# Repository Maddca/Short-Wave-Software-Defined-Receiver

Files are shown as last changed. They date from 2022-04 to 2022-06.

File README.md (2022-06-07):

# Short-Wave-Software-Defined-Receiver
The goal of this project has been to design a Software Defined Radio Receiver with [Taylor Smith](https://github.com/TaylorSmith28) for the Engineering Electronics II class.
## Design Objectives
For this project we were given the following design objectives by [Dr. Rob Frohne](https://github.com/frohro):

#### Objectives
 - Low noise figure
 - Good image rejection
 - Minimum discernible signal of less than 1uV
 - $25 Budget

For specifications we originally were going to have a narrow bandpass filter, but ended up switching to a relatively wider one in the later stages of the project.

#### Specifications
 - Frequency Range of 7-12MHz
 - Short Wave Radio
 - Uses a Tayloe Mixer
 - Uses a Multiple Feedback Lowpass Filter and Amplifier
 	- 25 V/V gain with Cutoff Frequency of more than 50KHz
 - Butterworth Bandpass Filter
 - Uses the Raspberry Pi Pico
 
 ## Overview
 The SDR receiver connects to an antenna and filters, mixes, and amplifies that signal to achieve the desired I and Q signals. The I and Q signals are then sent through an external sound card with a sample rate of 48kHz where software then handles the demodulation of the signal into audio. The mixer requires a 90 degree offset of two clocks operating at a frequency that can be controlled through software. In our design we use a Raspberry Pi Pico to control an si5351 to supply those two 90 degree offset clocks. There were some significant issues with this since the code supplied by professor Frohne didn't work when ported over to the Raspberry Pi Pico. In theory though the Raspberry Pi Pico interfaces with Quisk to tune to a certain frequency by adjusting the frequency of the si5351 clocks.
 
 ## Theory
SDR Block Diagram

The Block Diagram above shows the basics of how the SDR works. We get an input signal from the antenna which is passed through the bandpass filter and sent to the Tayloe Mixer that uses a 1:4 demultiplexer and low pass filters and ampliers to create the I and Q quardrature signals. After the demuiltiplexer creates 4 signals each 90 degrees out of phase with each other those signals are combined together to create the I and Q signals to be sent to the Audio Jack.

## Schematic Version 6

### Bandpass Filter
SDR BandPass Filter V6
 Above is the bandpass filter made using the [LC Filter Design Tool](https://rf-tools.com/lc-filter/.). It is a 3rd order, conventional series first, Butterworth, bandpass filter that passes 7-12Mhz frequencies.
 
 ### Tayloe Mixer
 SDR Tayloe Mixer
The Tayloe Mixer above is comprised of the Demultiplexer stage which seperates the input signal into four signals all 90 degrees out of phase with each other. Then the signals that are 180 degrees out of phase with each other are combined in the following amplifier and low pass filter stage using opamps. The filter/amplifier here is a multiple feedback low pass filter and amplifier, in this case multiple refers to the filter being second order rather than single order.

### Voltage Smoother
SDR Voltage Smoother
The voltage smoother above simply uses varying capacitor sizes to lower the noise coming from the USB.

### Oscillator
SDR Oscillator
The oscillator above is what outputs the clock signals necessary to run the Tayloe Mixer. It is controlled by the Raspberry Pi Pico on the SDA and SCL inputs.

### Raspberry Pi Pico
SDR Raspberry Pi Pico
Above is the part of the schematic dealing with the Raspberry Pi Pico. The main thing of interest here is to note the pull up resistors and the GPIO pin the SDA and SCL are connected to, since the pin needs to be I2C compatible, in this case pins 6 and 7 or GPIO 4 and 5 are I2C compatible.

## Simulations
Simulations were for the most part conducted in [LTSpice](https://www.analog.com/en/design-center/design-tools-and-calculators/ltspice-simulator.html).
### Bandpass Filter Simulations
SDR Bandpass Filter Sim Graph
SDR BandPass Filter LTSpice
The Bandpass filter was designed to pass frequencies between 7 and 12 MHz, which is what the ac simulation shows.

### Lowpass Filter Simulations
SDR MFLPFA Simulation Graph
SDR MFLPFA LTSpice

## Issues
The first major issue we encountered was not having functional code because of the port over to Raspberry Pi Pico. It took 2 days of troubleshooting to get the appropriate clock signal to display and thats still without the ability to change frequencies, which currently causes the program to hang. The second major issue was much simpler. When we went to test our bandpass filter we came to the realization that one of the leads on the handwound inductors couldn't make a good connection because there was still enamel on it. After several failed attempts to remove it we decided jump the bandpass filter, but much later discovered that shorting the bandpass filter with a wire caused one of the resistors responsible for the dc offset to be in parallel with the resistor in the signal generator. This caused us to lose our DC Offset which caused the SDR not to work. To resolve this issue we simply shorted the bandpass filter with a capacitor.
## Results
We ended up with a minimum discernable signal of approx 1uV and when we tried the antenna we listened to some Catholic sermon on sunday.
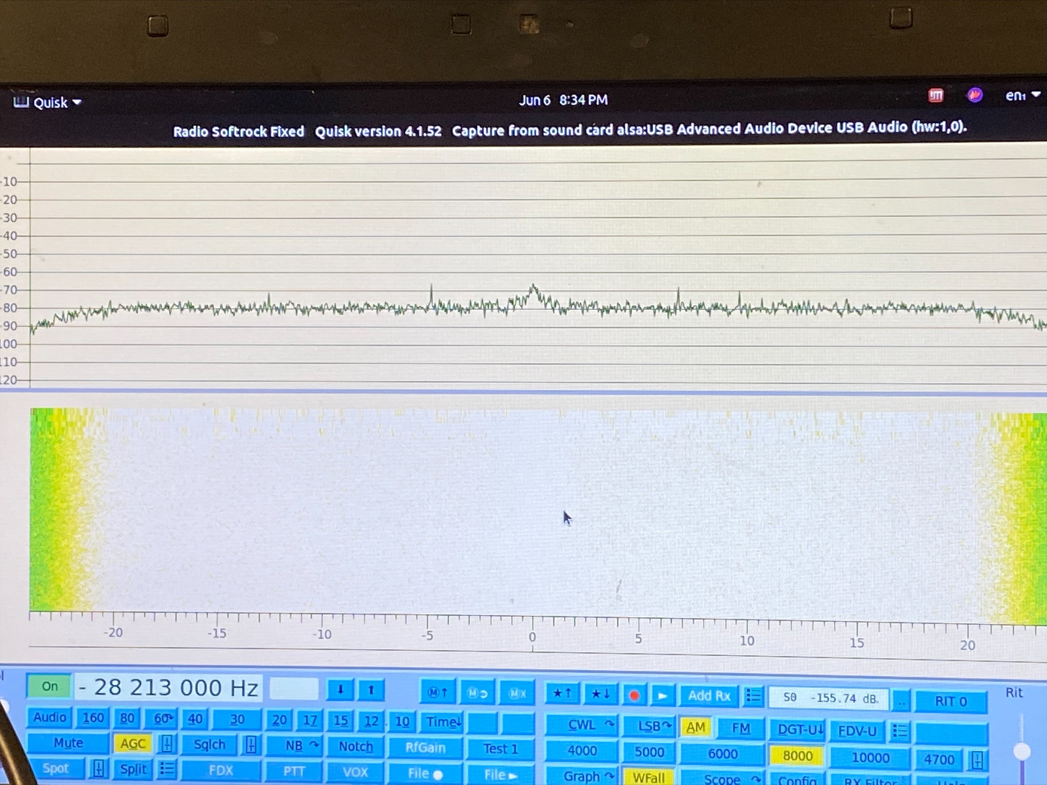
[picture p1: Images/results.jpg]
Frequency Test


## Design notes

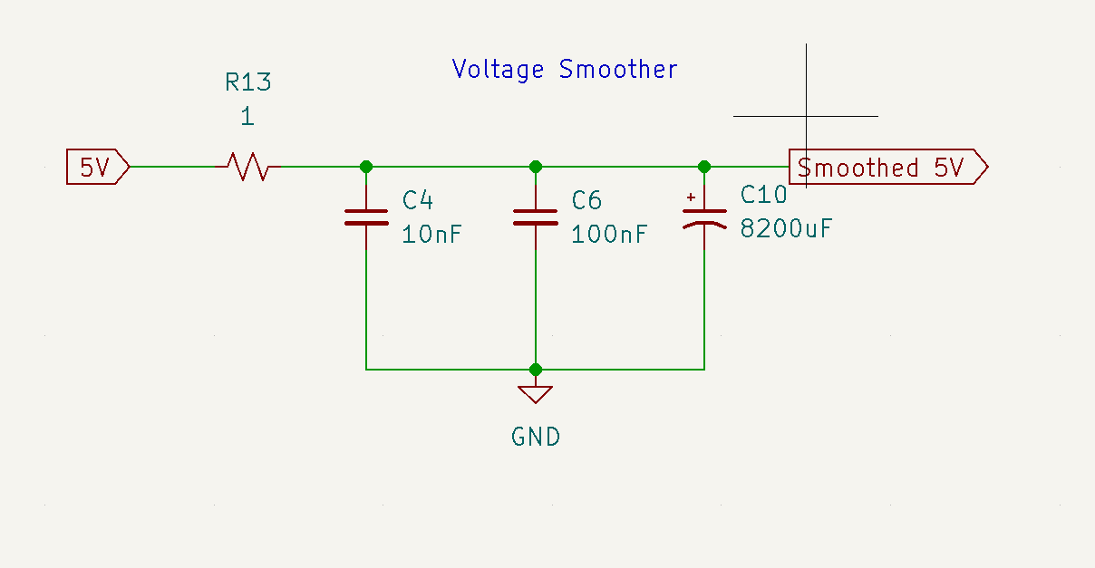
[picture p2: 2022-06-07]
Images/SDR Voltage Smoother.png

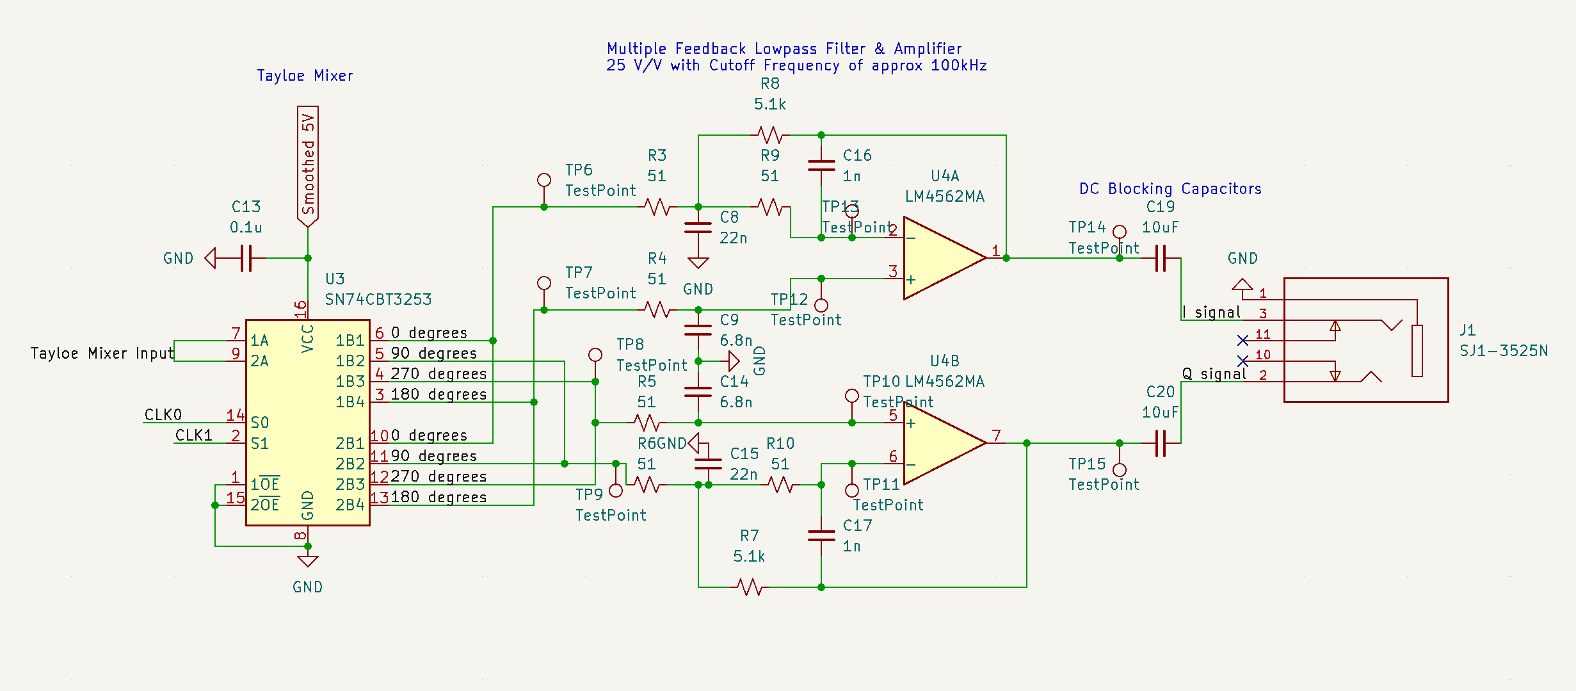
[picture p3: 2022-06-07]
Images/SDR Tayloe Mixer.png

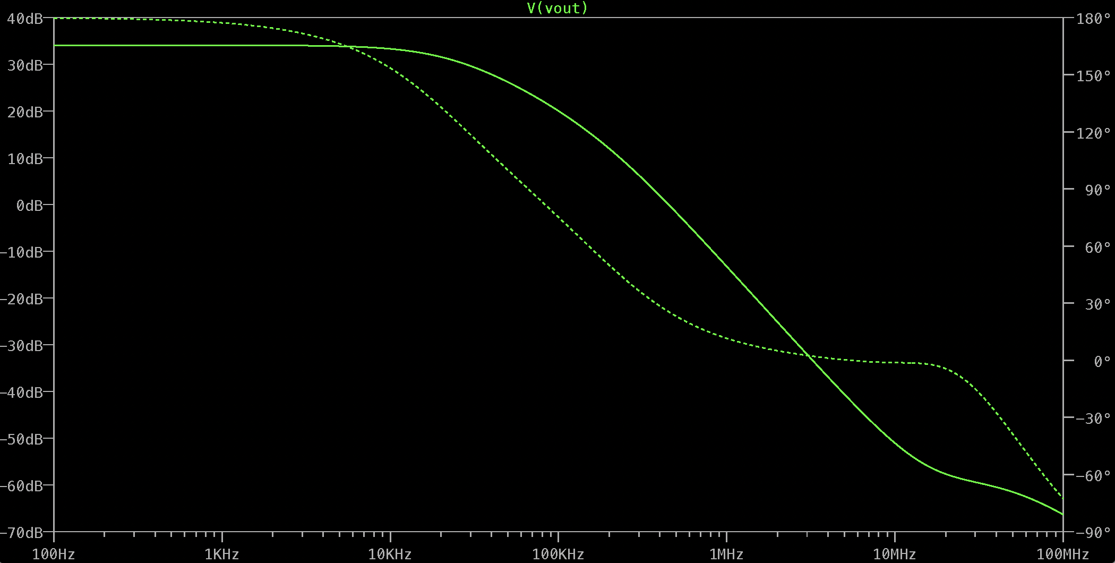
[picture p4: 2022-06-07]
Images/SDR MFLPFA Simulation Graph.png

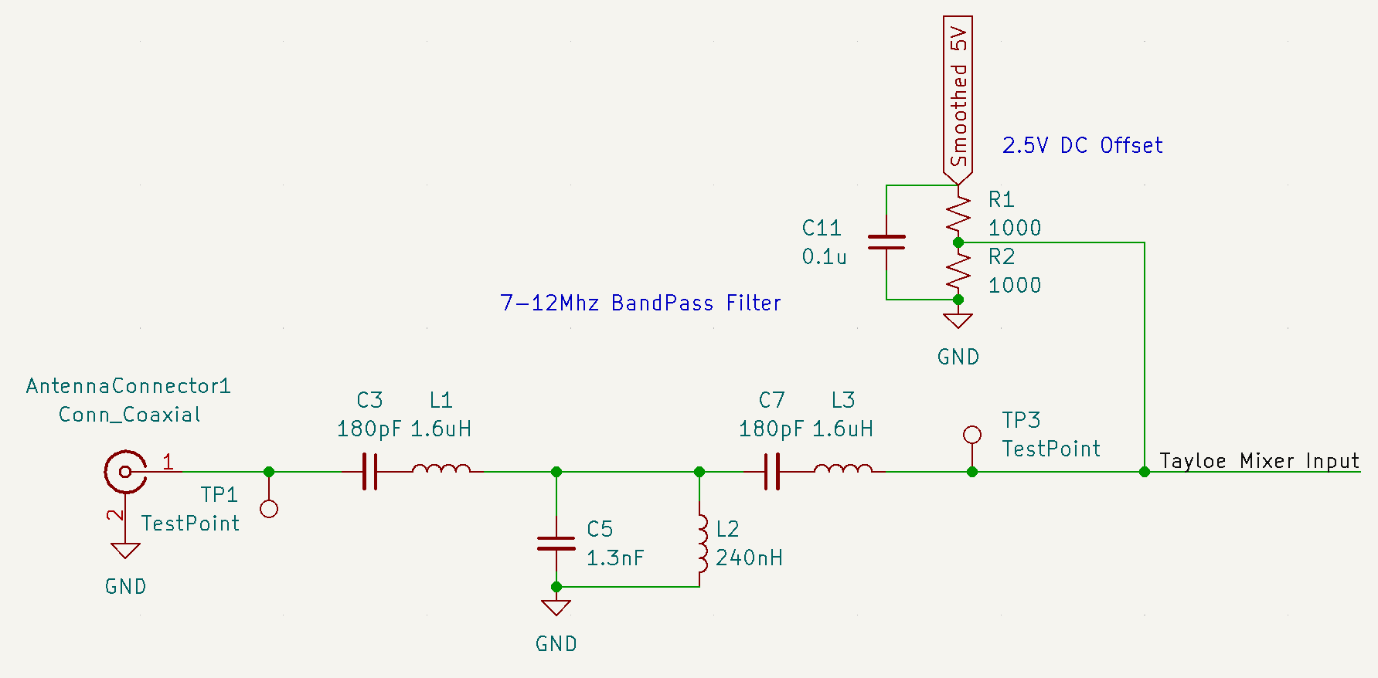
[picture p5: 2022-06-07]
Images/SDR BandPass Filter V6.png

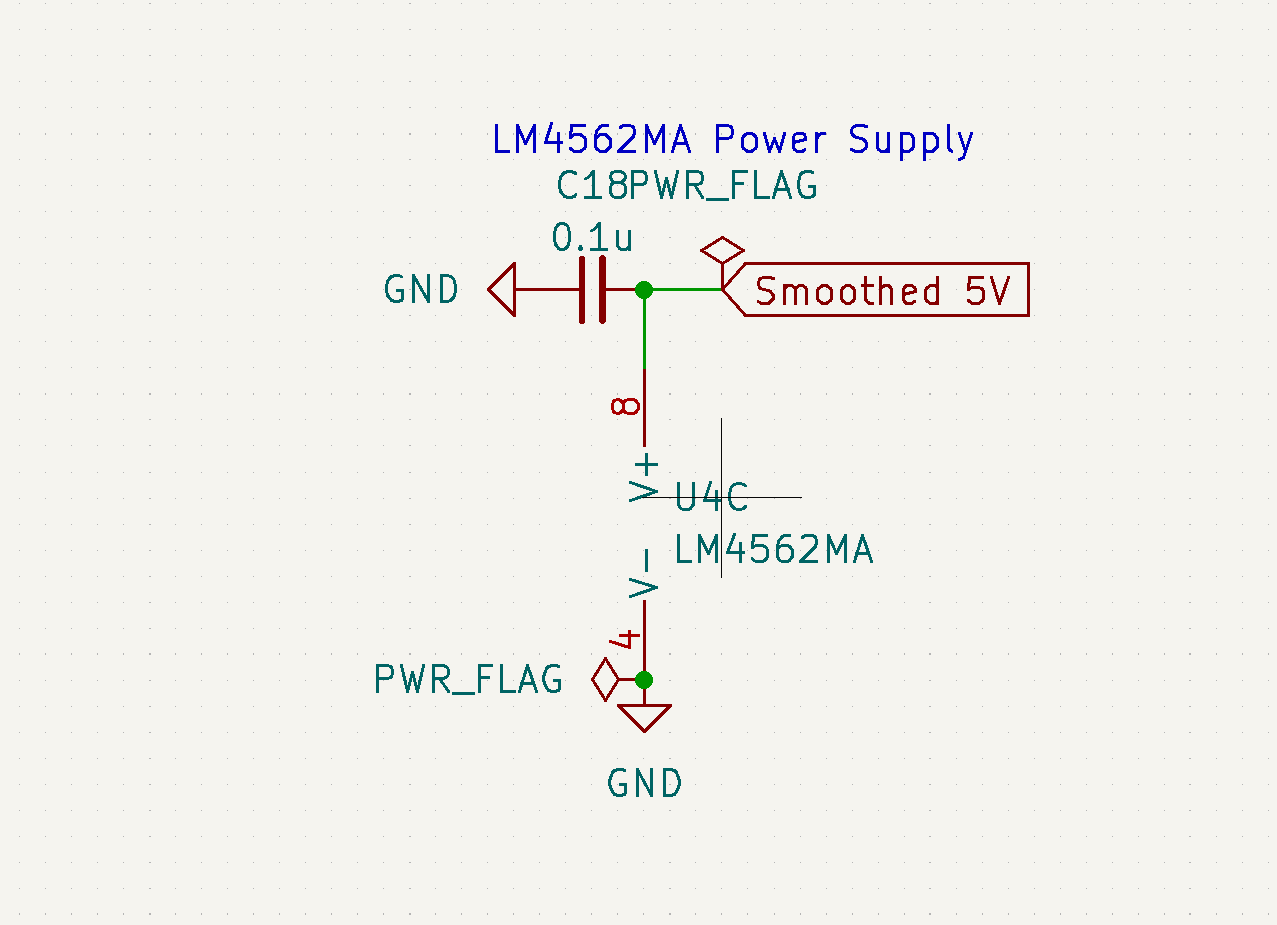
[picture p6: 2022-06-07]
Images/SDR OPamp Power Supply.png

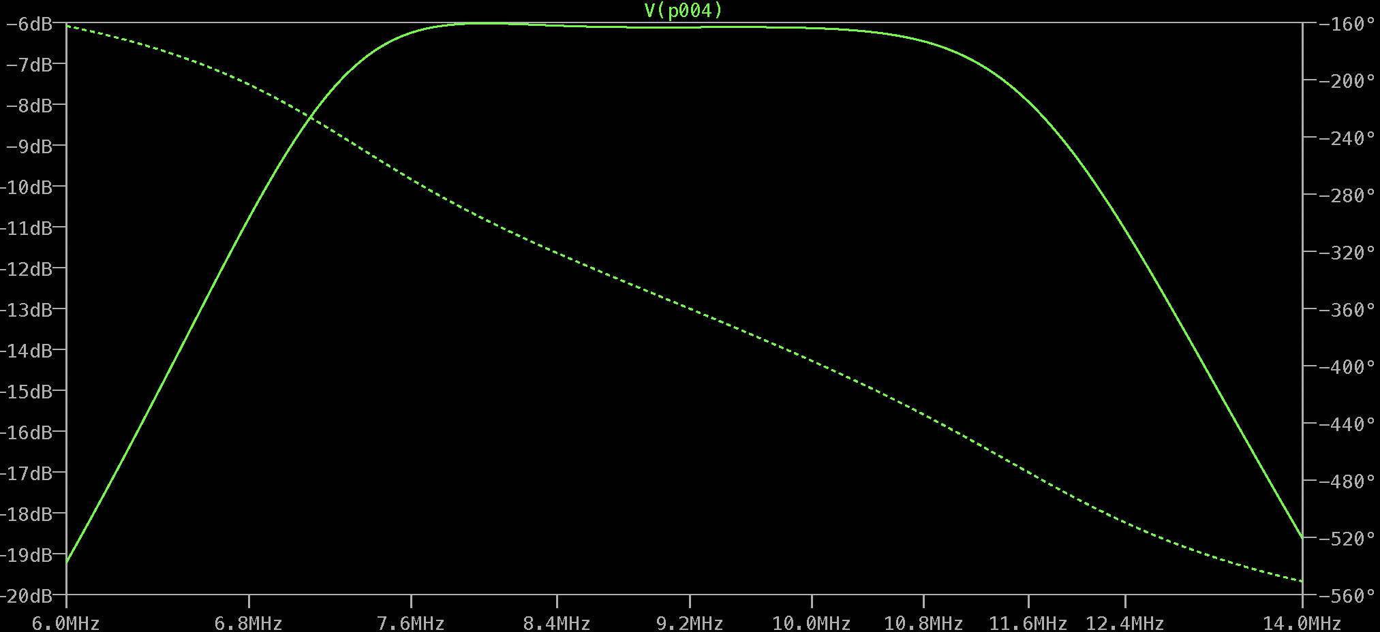
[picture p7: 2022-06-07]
Images/SDR Bandpass Filter Sim Graph.png

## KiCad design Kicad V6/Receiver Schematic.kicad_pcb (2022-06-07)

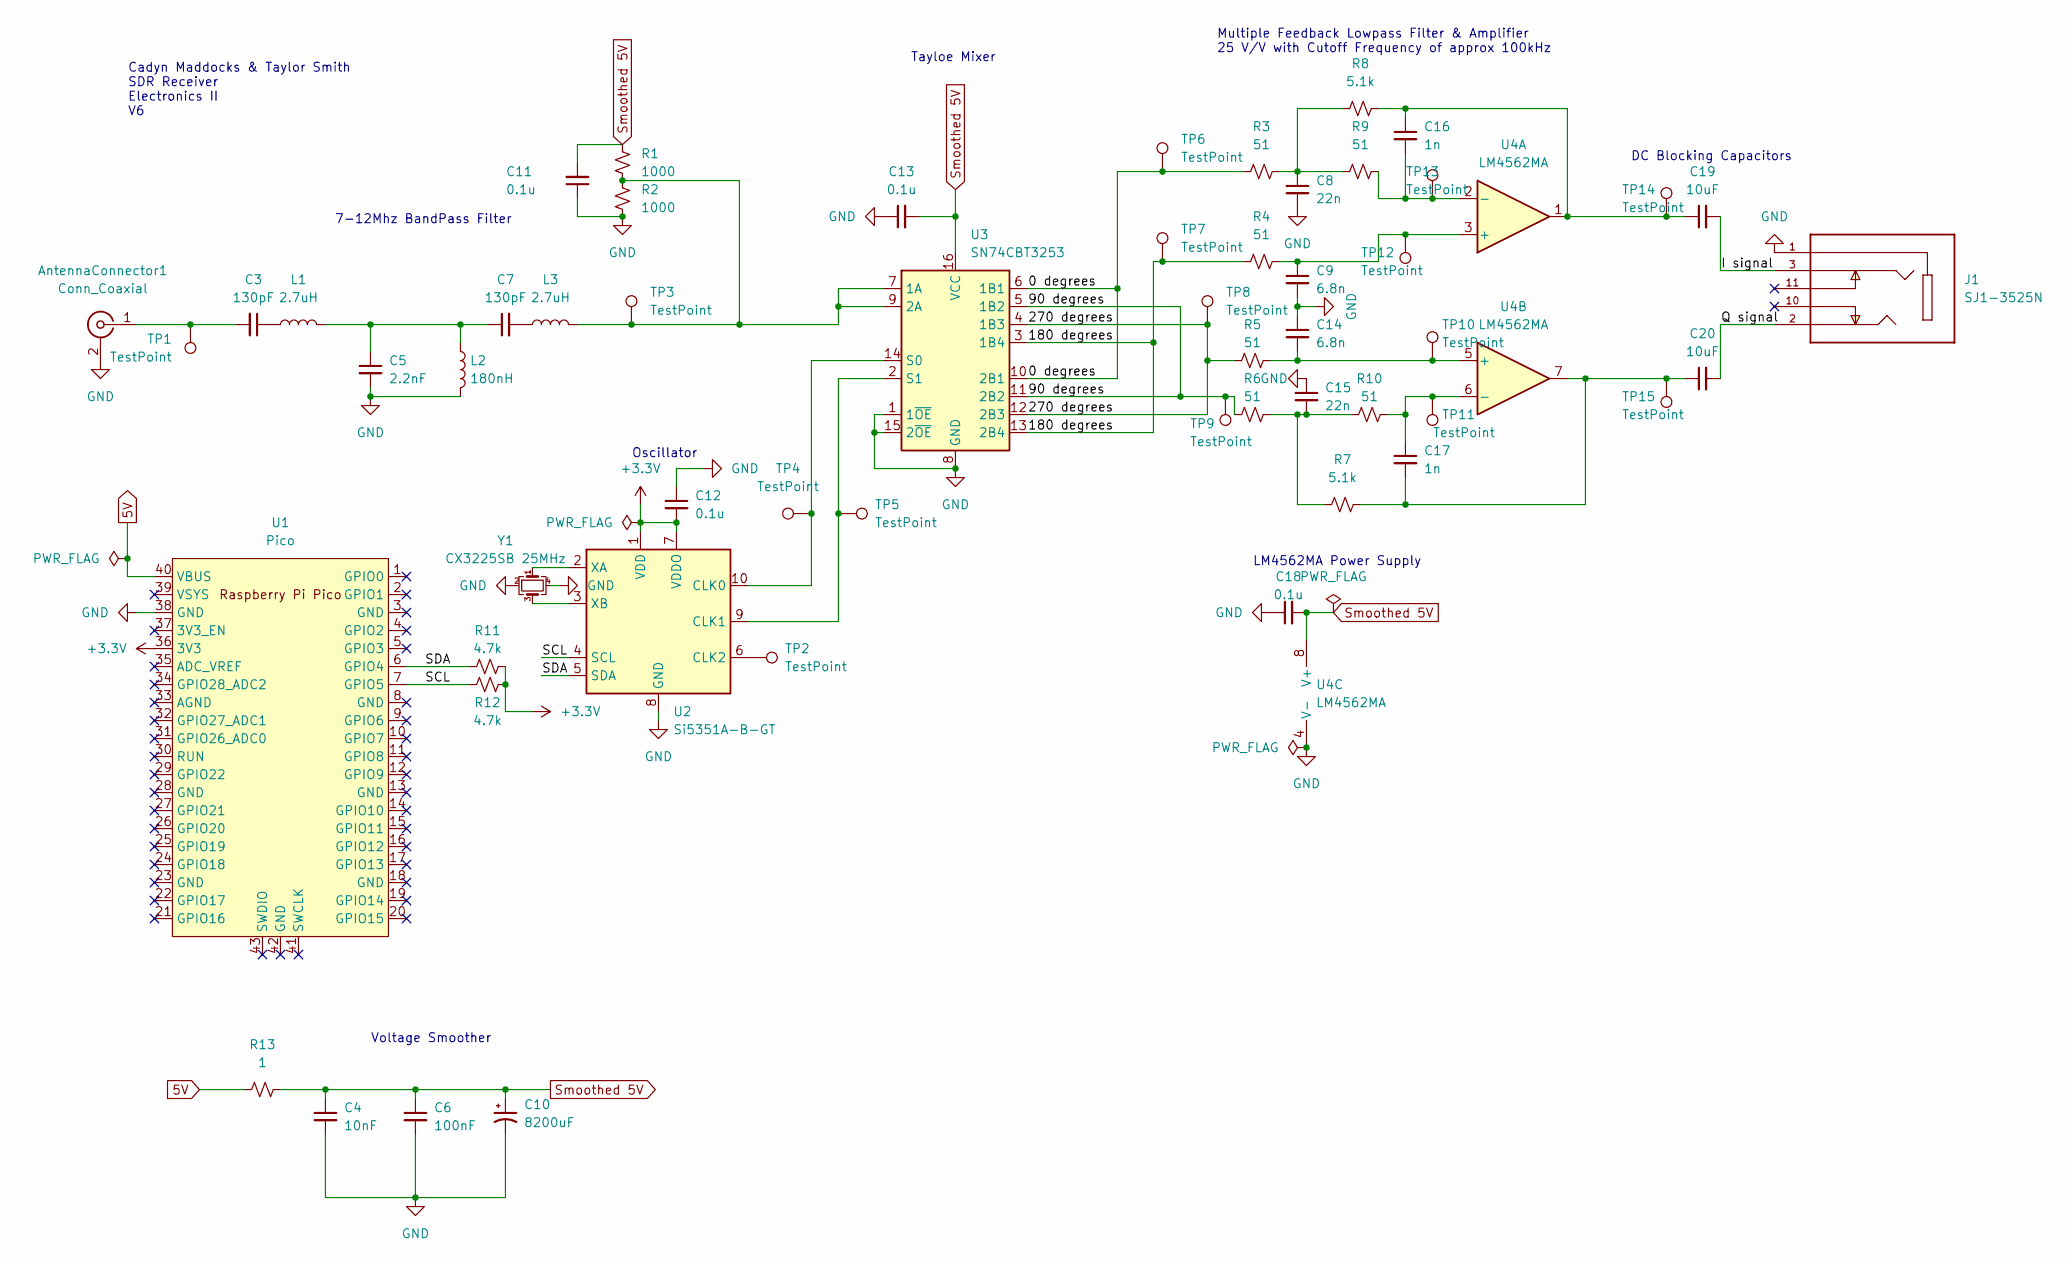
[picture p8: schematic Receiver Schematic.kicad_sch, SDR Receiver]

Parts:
AntennaConnector1: Conn_Coaxial; BNC_Amphenol_B6252HB-NPP3G-50_Horizontal
C3, C7: 130pF; C_0805_2012Metric
C4: 10nF; C_0805_2012Metric
C5: 2.2nF; C_0805_2012Metric
C6: 100nF; C_0805_2012Metric
C8, C15: 22n; C_0805_2012Metric
C9, C14: 6.8n; C_0805_2012Metric
C10: 8200uF; CP_Radial_D16.0mm_P7.50mm
C11, C12, C13, C18: 0.1u; C_0805_2012Metric
C16, C17: 1n; C_0805_2012Metric
C19, C20: 10uF; C_0805_2012Metric
J1: SJ1-3525N; CUI_SJ1-3525N; PARTREV 1.02
L1, L3: 2.7uH; L_Toroid_Vertical_L10.0mm_W5.0mm_P5.08mm
L2: 180nH; L_Toroid_Vertical_L10.0mm_W5.0mm_P5.08mm
R1, R2: 1000; R_0805_2012Metric
R3, R4, R5, R6, R9, R10: 51; R_0805_2012Metric
R7, R8: 5.1k; R_0805_2012Metric
R11, R12: 4.7k; R_0805_2012Metric
R13: 1; R_0805_2012Metric
TP1, TP2, TP3, TP4, TP5, TP6, TP7, TP8, TP9, TP10, TP11, TP12, TP13, TP14, TP15: TestPoint; TestPoint_THTPad_2.0x2.0mm_Drill1.0mm
U1: Pico; RPi_Pico_SMD_TH
U2: Si5351A-B-GT; MSOP-10_3x3mm_P0.5mm
U3: SN74CBT3253; SOIC-16_3.9x9.9mm_P1.27mm
U4: LM4562MA; SOIC-8_3.9x4.9mm_P1.27mm
Y1: CX3225SB 25MHz; Crystal_SMD_TXC_7M-4Pin_3.2x2.5mm

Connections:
5V: R13.1, U1.40 (VBUS)
+3V3: C12.2, R11.2, R12.2, U1.36 (3V3), U2.1 (VDD), U2.7 (VDDO)
/0 degrees: R3.1, TP6.1, U3.6 (1B1), U3.10 (2B1)
/90 degrees: R6.1, TP9.1, U3.5 (1B2), U3.11 (2B2)
/180 degrees: R4.1, TP7.1, U3.3 (1B4), U3.13 (2B4)
/270 degrees: R5.1, TP8.1, U3.4 (1B3), U3.12 (2B3)
/I signal: C19.2, J1.3
/Q signal: C20.2, J1.2
/SCL: R12.1, U1.7 (GPIO5), U2.4 (SCL)
/SDA: R11.1, U1.6 (GPIO4), U2.5 (SDA)
GND: AntennaConnector1.2 (Ext), C4.2, C5.2, C6.2, C8.2, C9.2, C10.2, C11.1, C12.1, C13.1, C14.1, C15.1, C18.1, J1.1, L2.2, R2.2, U1.38 (GND), U2.8 (GND), U3.1 (1~OE), U3.8 (GND), U3.15 (2~OE), U4.4 (V-), Y1.2, Y1.4
unnamed: AntennaConnector1.1 (In), C3.2, TP1.1
unnamed: C3.1, L1.1
unnamed: C5.1, C7.1, L1.2, L2.1
unnamed: C7.2, L3.1
unnamed: C8.1, R3.2, R8.1, R9.1
unnamed: C9.1, R4.2, TP12.1, U4.3 (+)
unnamed: C14.2, R5.2, TP10.1, U4.5 (+)
unnamed: C15.2, R6.2, R7.1, R10.1
unnamed: C16.1, C19.1, R8.2, TP14.1, U4.1
unnamed: C16.2, R9.2, TP13.1, U4.2 (-)
unnamed: C17.1, R10.2, TP11.1, U4.6 (-)
unnamed: C17.2, C20.1, R7.2, TP15.1, U4.7
unnamed: L3.2, R1.2, R2.1, TP3.1, U3.7 (1A), U3.9 (2A)
unnamed: TP2.1, U2.6 (CLK2)
unnamed: TP4.1, U2.10 (CLK0), U3.14 (S0)
unnamed: TP5.1, U2.9 (CLK1), U3.2 (S1)
unnamed: U2.2 (XA), Y1.1
unnamed: U2.3 (XB), Y1.3
Smoothed 5V: C4.1, C6.1, C10.1, C11.2, C13.2, C18.2, R1.1, R13.2, U3.16 (VCC), U4.8 (V+)

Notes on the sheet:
Multiple Feedback Lowpass Filter & Amplifier 25 V/V with Cutoff Frequency of approx 100kHz
Oscillator
LM4562MA Power Supply
Tayloe Mixer
7-12Mhz BandPass Filter
DC Blocking Capacitors
Voltage Smoother
Cadyn Maddocks & Taylor Smith SDR Receiver Electronics II V6

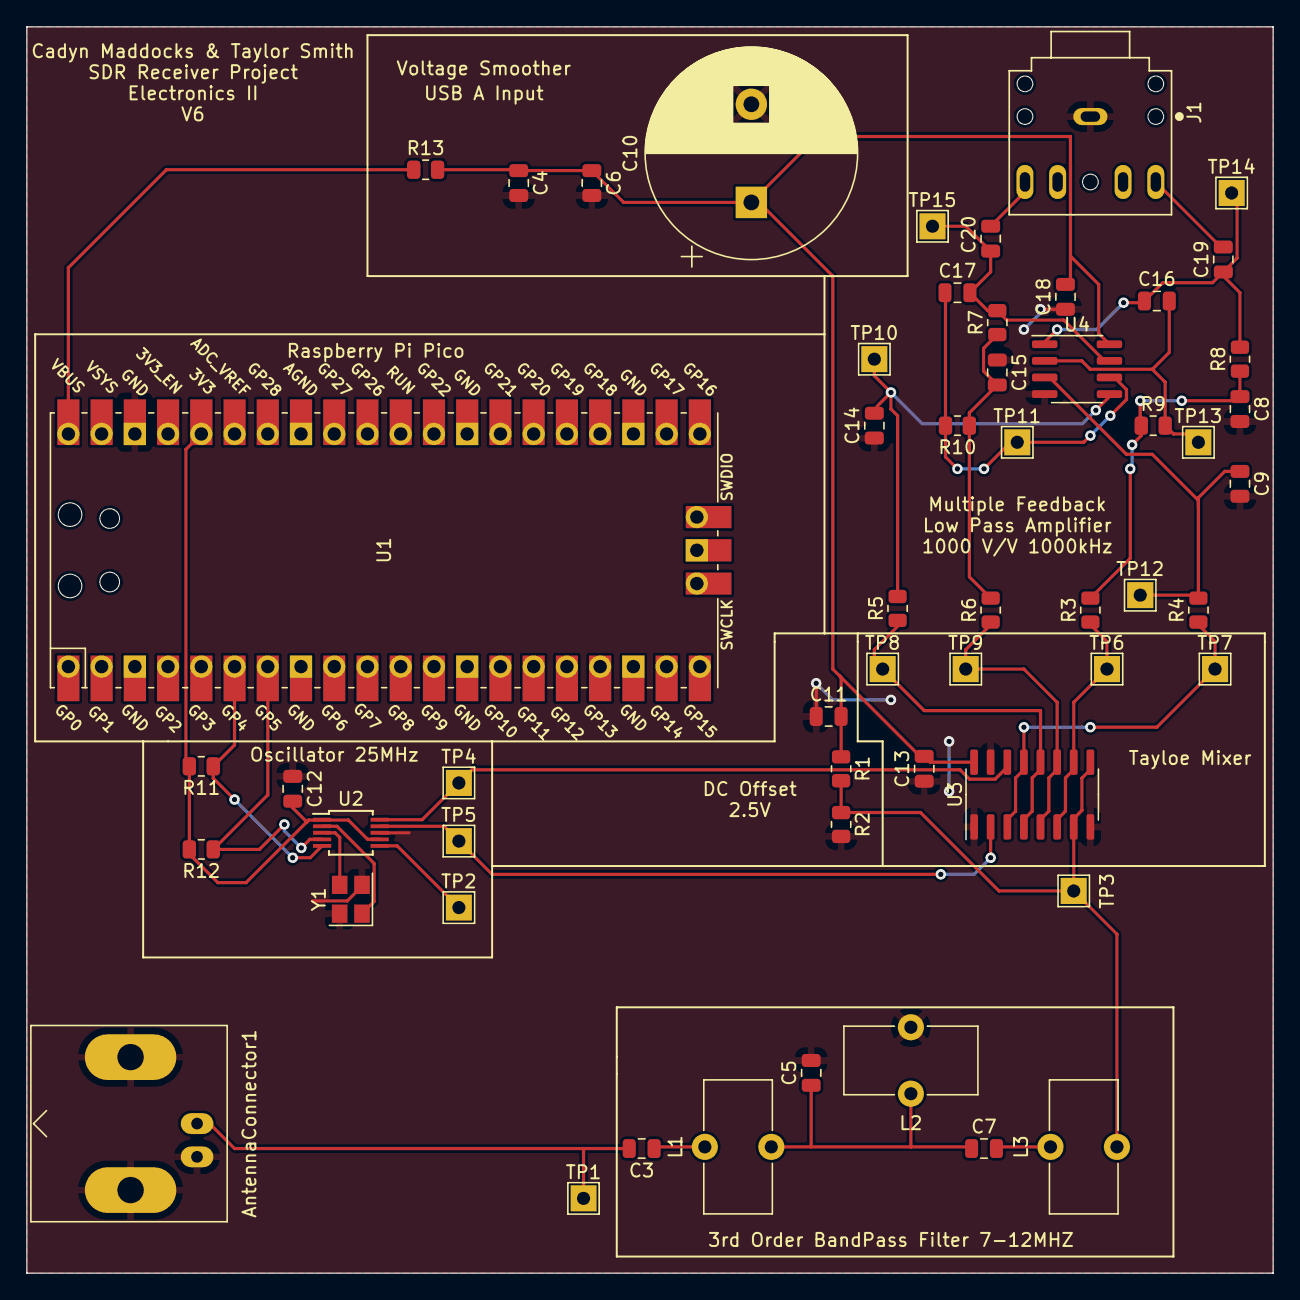
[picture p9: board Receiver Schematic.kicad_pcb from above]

Board: 2 copper layers, 95.3 x 95.2 mm, 56 parts (0 on the bottom side), 30 nets.

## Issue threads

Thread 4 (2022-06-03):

Noise issues

Maddca, 2022-06-03:
Despite fairly low noise on the low pass amplifier simulations, we're getting way higher noise levels than simulations predicted. Possible solutions include increasing gain, switching to a lower noise op amp, and finding and eliminating other sources of noise.
The noise on the output is around 10uV and the simulations show values of 1-2uV, depending on the version.

Maddca, 2022-06-05:
Discovered that the problem wasn't necessarily the noise, removing the potential ground loops caused no significant changes. Instead the problem turned out to be caused by shorting the bandpass filter in the beginning, which we had done because of a faulty connection with the inductor. We needed to short it with a capacitor instead of a wire since using a wire caused the resistor in the frequency generator to be in parallel with one of our dc offset resistors essentially causing us to lose our dc offset entirely.

Closed 2022-06-05.

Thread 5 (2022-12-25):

Problems with the Etherkit Si5351 Library

frohro, 2022-12-25:
Hi Cadyn,
I noted today that it looks like a [person got the Etherkit library to work with the Si5351](https://www.youtube.com/watch?v=R5qr2HKmTQY).  They used GPIO20 and GPIO21, not the ones you used.  You can change them with something like:
`Wire.setSDA(20);
Wire.setSCL(21);`
The 20 and 21 are the GPIO numbers, not the pin numbers.  You need to change the pin numbers to 4 and 5 respectively to match your PCB.
He is using the Earl E. Philhower library to build the code.
Rob

frohro, 2023-10-30:
I played with it again, and I think the regular MBED library for the pico works now.  We can close this.

Closed 2023-10-30.

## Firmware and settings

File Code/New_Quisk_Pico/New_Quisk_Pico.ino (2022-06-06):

#include <si5351.h>

#include <si5351.h>


/*
  OpenRadio Quisk Interface 
  Main
  This is used to provide a serial interface which Quisk SDR can talk to.
  
  Copyright (C) 2014 Mark Jessop <vk5qi@rfhead.net>

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
    For a full copy of the GNU General Public License, 
    see <http://www.gnu.org/licenses/>.

   Command Reference:
    ------------------
    All commands consist of an identifier, followed by one or more parameters delinieated by commas, then a newline.
    i.e.:
    COMMAND,<param1>,<param2><LF>
    
    A command will return OK<LF> if successful, and ERROR<LF> if not. Some commands (particuarly transmit commands)
    may take a significant amount of time to return.
    
    Sending a command which takes parameters, without sending the parameters, will return the set parameters.
    
    Frequency Settings:
    
    FREQ,<freq>     - Set the center freq of the receiver, in Hz.
    FREQPSK,<freq>    - Set the transmit frequency, in Hz.

    Modulation:
    All transmissions will time out after 10 minutes. (if we implement it)
    
    CARRIER,<ON/OFF>  - Transmit a carrier.
    PSK,<rate>,message  - Send message using Phase Shift Keying, with the specified symbol rate.

    This version is made for the Rasbperry Pi Pico using the MBED OS..
*/

#include <Arduino.h>

//#warning __PGMSPACE_H_

//#include <EEPROM.h>
#include <Wire.h>

#include "si5351.h"

#include "settings.h"
#include "pins.h"
//#include "ring_buffer.h"

#define VERSION "0.3"

//#define USE_JOHNSON_COUNTER
// Default output frequency
#define RX_FREQ 14200000
#define TX_FREQ 14200000
#define FREQ_LIMIT_LOWER 100000
#define FREQ_LIMIT_UPPER 30000000 

#define SERIAL_BAUD     57600

Si5351 si5351(0x60);

uint8_t si5351_init();
int parseFreq(String input);
int parseCarrier(String carrier_str);
int set_channel(String input);

int tx_relay_state = 0;
int tx_state = 0;

static struct settings settings;

// Ring buffer for use with the interrupt-driven transmit buffer.
//struct ring_buffer data_tx_buffer = { { 0 }, 0, 0};

/* Returns true if settings are valid */
//static bool read_settings(void)
//{
//    uint8_t *p = (uint8_t *)&settings;
//    int i = 0;
//
//    while(i < sizeof(struct settings))
//        *p++ = EEPROM.read(i++);
//
//    return settings.magic == SETTINGS_MAGIC;
//}

//static void write_settings(void)
//{
//    uint8_t *p = (uint8_t *)&settings;
//    int i = 0;
//
//    // Invalidate checksum to guard against partial writes
//    EEPROM.write(0, 0);
//
//    while(i < sizeof(struct settings))
//        EEPROM.write(i++, *p++);
//}

// Input buffer for reading user input.
#define INPUTBUFLEN 64
//char inputBuffer[INPUTBUFLEN];
int inputBufferPtr = 0;
char tempBuffer[20]; // Buffer for string to int conversion.
String inputBuffer = "";

void setup(){
    // Initialise things.
    pinMode(TX_RX_SWITCH, OUTPUT);
    digitalWrite(TX_RX_SWITCH, LOW);
    pinMode(MODULATION, OUTPUT);
    digitalWrite(MODULATION, LOW);
    pinMode(LED, OUTPUT);
    digitalWrite(LED, LOW);

    Serial.begin(SERIAL_BAUD);
    Serial.setTimeout(1000 * 10);

    uint8_t rev_id = si5351_init();
    
    // Click the relay as an 'audible' startup indicator.
    digitalWrite(TX_RX_SWITCH, HIGH);
    delay(300);
    digitalWrite(TX_RX_SWITCH, LOW);
    


// Perform Si5351 calibration
//    uint64_t rx_freq = 1000024200ULL;  // Where you receive WWV before calibration...
//    uint64_t target_freq = 1000000000ULL; // 10 MHz, in hundredths of hertz
//    uint32_t cal_factor = (int32_t)(target_freq - rx_freq);
//    //si5351.set_correction(cal_factor, SI5351_PLL_INPUT_XO);
//    
//    si5351.set_pll(SI5351_PLL_FIXED, SI5351_PLLA);
//    si5351.pll_reset(SI5351_PLLA);

   //    if (!read_settings()) {
        //Serial.println(F("Resetting settings to defaults"));
//        settings.magic = SETTINGS_MAGIC;
//        settings.rx_freq = RX_FREQ;
        //settings.tx_freq = TX_FREQ;
        //settings.cal_factor = cal_factor;
//    }
    
    //set_rx_freq(settings.rx_freq);
    //set_tx_freq(settings.tx_freq);
}

void loop(){
  if(Serial.available()){
    // Read in a byte.
    char inChar = (char)Serial.read();
    
    // Work out what the character is. If letters or numbers, add to
    // the buffer, if not, don't add.
    
    // If character is a newline, we have reached the end of the command.
    if( (inChar == '\n') || (inputBufferPtr>INPUTBUFLEN)){
      // Parse string
      if( parseCommand(inputBuffer)==0 ){
        Serial.println("OK");
      }else{
        Serial.println("ERROR");
      }
      inputBuffer = "";
      inputBufferPtr = 0;
    }else if( isalnum(inChar) || ispunct(inChar) || isblank(inChar) || inChar==4 ){
      // Add to the input buffer if printable and not a line ending.
      inputBuffer += inChar;
      inputBufferPtr++;
    }
  }
}

// CSV parser function. Splits input into arguments.
// I am so sorry...
int parseCommand(String input){
  int params = 0;
  
  if(input.length()<3){
    // No command is shorter than 3 characters. Error.
    return 1;
  }
  // At this point we have found some sort of command (maybe)
  

  // Search through for commas, populate an array of pointers, make pointer = -1 if nothing found.
  // NOTE: This is a horrible bit of code. If theres is a better way to do CSV parsing in Arduino, let me know!
  int separators[] = {-1,-1,-1,-1,-1,-1};

  separators[0] = input.indexOf(",");
  
  if(separators[0] != -1){ // If we find one comma, maybe there are more...
    int i = 1;
    while((separators[i-1] != -1) && i<6){
      params++;
      separators[i] = input.indexOf(",", separators[i-1]+1);
      i++;
    }
  
  }

  if(params==0){ // Either a request command or a command with no parameter
    if(input.startsWith("FREQPSK")){
      Serial.print("FREQPSK,"); Serial.println(settings.tx_freq);
      return 0;
    }else 
    if(input.startsWith("FREQ")){
      Serial.print("FREQ,"); Serial.println(settings.rx_freq);
      return 0;
    }else if(input.startsWith("CAL")){
      Serial.print("CAL,"); Serial.println(settings.cal_factor,10);
      return 0;
    }else if(input.startsWith("VER")){
      Serial.print("VER,"); Serial.println("OpenRadio V1.1");
      return 0;
    }else{
      // No other commands are valid without parameters. Error
      return 1;
    }
  }else if(params==1){ // Commands with one argument.
    String param1 = input.substring(separators[0]+1); // Extract the argument for passing to the function.
    if(input.startsWith("FREQPSK")){
//      return parsePSKFreq(param1);
    }else if(input.startsWith("FREQ")){
      return parseFreq(param1);
    }
    else if(input.startsWith("PSKFREQ")){
//      return parsePSKFreq(param1);
    }else if(input.startsWith("CARRIER")){
      return parseCarrier(param1);
    }else if(input.startsWith("CHAN")){
      return set_channel(param1);
    }else{
      // No other commands are valid with only one parameter. Error
      return 1;
    }
  }
//  else if(params==2){ // Commands with 2 parameters (PSK);
//    String param1 = input.substring(separators[0]+1, separators[1]);
//    String param2 = input.substring(separators[1]+1);
//    
//    if(input.startsWith("PSK")){
//      return psk_transmit(param1,param2);
//    }else{
//      // No other commands are valid with only one parameter. Error
//      return 1;
//    }
//  }

  return 1; // Cannot parse command, error.
}

int freqValid(uint32_t freq){
  return (freq>FREQ_LIMIT_LOWER) && (freq<FREQ_LIMIT_UPPER);
}

// Parse frequency, program radio.
int parseFreq(String input){
  unsigned long result = 0;
  unsigned long combinedresult = 0;
  char* endptr;
  
  input.toCharArray(tempBuffer,10);
  
  result = strtoul(tempBuffer,&endptr,10);
  // If strtoul fails to convert, *endptr contains the character which conversion failed on.
  // Otherwise, *endptr contains '\0'.
  if(*endptr != 0) return -1;
  
  if(freqValid(result)){
    set_rx_freq(result);
    Serial.print("FREQ,");Serial.println(result);
    return 0;
  }else{
    //Serial.println("Invalid input.");
    return -1;
  } 
}

// Carrier on/off
// This should transmit a carrier at an offset from the rx freq.
// We probably dont need this right now.
int parseCarrier(String carrier_str){
// TODO
  return -1;
}

// Transit a string of PSK (message) at (rate) baud.
// We need to figure out how to decide what the 'offset' from the RF freq is.
// Maybe add another command to set this?
int parsePSK(String rate, String message){
// TODO
  return -1;
}

// Set the frequency of the transmitted PSK signal.
// This is entirely independent of the receive chain, and we should
// be controlling if we want to lock this to within the RX passband 
// from within the client software.
int parsePSKFreq(String input){
  unsigned long result = 0;
  unsigned long combinedresult = 0;
  char* endptr;
  
  input.toCharArray(tempBuffer,10);
  
  result = strtoul(tempBuffer,&endptr,10);
  // If strtoul fails to convert, *endptr contains the character which conversion failed on.
  // Otherwise, *endptr contains '\0'.
  if(*endptr != 0) return -1;
  
  if(freqValid(result)){
    set_tx_freq(result);
    Serial.print("FREQPSK,");Serial.println(result);
    return 0;
  }else{
    //Serial.println("Invalid input.");
    return -1;
  } 

}


//
// Si5351 Helper Functions
//

uint8_t si5351_init(){
    si5351.init(SI5351_CRYSTAL_LOAD_8PF,0,0);
    si5351.set_pll(SI5351_PLL_FIXED, SI5351_PLLA);
    // Set output frequencies
    while(!Serial);
    set_rx_freq(RX_FREQ);
    //set_tx_freq(TX_FREQ);
    
    // Enable RX, and disable TX by default.
 //   si5351.output_enable(SI5351_CLK0,1);
  //  si5351.output_enable(SI5351_CLK1,0);
//    si5351.output_enable(SI5351_CLK2,0);
    // Read the status register and return the chip revision ID.
   Serial.println("Before update status");
  si5351.update_status();
   Serial.println(si5351.dev_status.REVID);

    return si5351.dev_status.REVID;

}

static void set_rx_freq(uint32_t freq)
{
    // Save actual value
  //  settings.rx_freq = freq;

#ifdef USE_JOHNSON_COUNTER
    // This is for models where quadrature mixer requires a 4X LO signal.
    si5351.set_freq(freq * 4, RX_CLOCK);
#else
 // This is for models that use the Si5351 to produce the I/Q on CLK0 and CLK1.
  uint64_t pll_freq;
  uint_fast8_t mult;
  // mult must be less than 128 (7 bits) according to documentation
  if (freq >= 26470588){
    mult = 22;
  } else if (freq >= 18000000) {
    mult = 34;
  } else if(freq > 12000000) {
    Serial.println("in the right multiplier.");
    mult = 50;
  } else if (freq >= 8000000) {
    mult = 75;
  } else if (freq > 5357143) {
    mult = 112;
  } else {
    mult = 128;
  }
  freq = (uint64_t) (freq*100ULL);
  pll_freq = (uint64_t)mult*freq;
  Serial.println("Before set_freq_manual");
  si5351.set_freq_manual(freq, pll_freq, SI5351_CLK0);
  si5351.set_freq_manual(freq, pll_freq, SI5351_CLK1);
  // Now we can set CLK1 to have a 90 deg phase shift by entering
  // mult in the CLK1 phase register, since the ratio of the PLL to
  // the clock frequency is mult.
  si5351.set_phase(SI5351_CLK0, 0);
  si5351.set_phase(SI5351_CLK1, mult);
  // We need to reset the PLL before they will be in phase alignment
  si5351.pll_reset(SI5351_PLLA);
#endif
if (freq <= 4.0e6){  // Set the band for the RX filters on the IQ_SDR
    digitalWrite(4, HIGH);
    digitalWrite(5, HIGH);
    }
if ((freq <= 8.0e6)&&(freq > 4.0e6)){
    digitalWrite(4, LOW);
    digitalWrite(5, HIGH);
    }
if ((freq <= 16.0e6)&&(freq > 8.0e6)){
    digitalWrite(4, HIGH);
    digitalWrite(5, LOW);
    }
else {
    digitalWrite(4, LOW);
    digitalWrite(5, LOW);
    }       
}

static void set_tx_freq(uint32_t freq)
{
    // Save actual value
    settings.tx_freq = freq;

    // Let driver choose PLL settings. May glitch when changing frequencies.
    si5351.set_freq(freq, (si5351_clock)0);
}

void tx_enable(){
    si5351.output_enable(TX_CLOCK,1);
    tx_state = 1;
}

void tx_disable(){
    si5351.output_enable(TX_CLOCK,0);
    tx_state = 0;
}

void tx(){
    digitalWrite(TX_RX_SWITCH, HIGH);
    digitalWrite(LED, HIGH);
    tx_relay_state = 1;
}

void rx(){
    digitalWrite(TX_RX_SWITCH, LOW);
    digitalWrite(LED, LOW);
    tx_relay_state = 0;
}

#define MIN_CHANNEL 1
#define MAX_CHANNEL 30


#ifdef USE_FLASH
// From https://docs.google.com/spreadsheets/d/1KP5XsAHPCD2FsUW5RoqCfCJYRt2o03q6RN2TroPgEKk/edit#gid=0
const prog_uint16_t channel_list[] =
#else
const uint16_t channel_list[] =
#endif
        {8986, 8990, 8993, 8996, 9000, 9003, 9006, 9010, 9013, 9016, 9020, 9023, 9026,
        9030, 9033, 9036, 9040, 9043, 9046, 9050, 9053, 9056, 9060, 9063, 9066, 9070,
        9073, 9076, 9080, 9083};

int set_channel(String input)
{
  unsigned long chan = 0;
  char* endptr;
  
  input.toCharArray(tempBuffer,10);
  
  chan = strtoul(tempBuffer,&endptr,10);
  // If strtoul fails to convert, *endptr contains the character which conversion failed on.
  // Otherwise, *endptr contains '\0'.
  if(*endptr != 0) return -1;



    if (chan < MIN_CHANNEL || chan > MAX_CHANNEL) {
        return 1;
    }

#ifdef USE_FLASH
    uint32_t rx = (uint32_t)pgm_read_word_near(channel_list + chan-1) * 1000;
#else
    uint32_t rx = (uint32_t)channel_list[chan-1] * 1000;
#endif
    uint32_t tx = rx * 3 + 1500;

    set_rx_freq(rx);
    set_tx_freq(tx);

    // Save settings
//    write_settings();

    Serial.print("CHAN,"); Serial.println(chan);
    return 0;
}

//int psk_transmit(String param1, String param2){
//  unsigned long baud_rate = 0;
//  char* endptr;
//  
//  param1.toCharArray(tempBuffer,10);
//  
//  baud_rate = strtoul(tempBuffer,&endptr,10);
//  // If strtoul fails to convert, *endptr contains the character which conversion failed on.
//  // Otherwise, *endptr contains '\0'.
//  if(*endptr != 0) return -1;
//
//    tx();
//    tx_enable();
//    if (!bpsk_start(baud_rate)){
//      tx_disable();
//      rx();
//        return 1;
//    }
//    delay(300); //  Short delay for RX sync to occur.
//    // Push string into ring buffer for transmission.
//    for(int i = 0; i<param2.length(); i++){
//      store_char(param2.charAt(i),&data_tx_buffer);
//    }
//    // Send an EOT control character, then a newline, to signify the end of the message.
//    store_char((char)4, &data_tx_buffer);
//    store_char('\n', &data_tx_buffer);
//    while(data_waiting(&data_tx_buffer)>0){}
//    delay(300);
//    bpsk_stop();
//    tx_disable();
//    rx();
//
//    return 0;
//}

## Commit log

2022-04-28 Receiver Schematic V1
    The first version of the quadrature sampling downconversion software defined receiver uploaded to the GitHub project page.
    [Receiver Schematic.kicad_pcb, Receiver Schematic.kicad_sch]
2022-04-28 First version with a pcb
    V3
    [Receiver Schematic.kicad_pcb, Receiver Schematic.kicad_sch]
2022-04-29 V4
    V4
    [Receiver Schematic.kicad_pcb, Receiver Schematic.kicad_sch]
2022-06-06 Version 5
    Updated File organization and minor fixes.
    [Receiver Schematic-B_Cu.gbr, Receiver Schematic-B_Mask.gbr, Receiver Schematic-B_Paste.gbr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]
2022-06-06 Further Updated schematic to resemble current board layout
2022-06-07 Final Schematic/PCB version
    Version 6 of the SDR Design
    [Receiver Schematic-B_Cu.gbr, Receiver Schematic-B_Mask.gbr, Receiver Schematic-B_Paste.gbr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]
2022-06-07 Block Diagram Upload
    [Receiver Schematic.kicad_sch]
2022-06-07 Added Bandpass filter simulation
    [Receiver Schematic.kicad_sch]

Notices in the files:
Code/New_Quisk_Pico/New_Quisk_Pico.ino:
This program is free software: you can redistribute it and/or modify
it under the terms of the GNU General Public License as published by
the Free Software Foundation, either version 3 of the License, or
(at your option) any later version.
